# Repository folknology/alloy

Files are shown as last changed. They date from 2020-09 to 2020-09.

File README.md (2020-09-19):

# Alloy
Alloy an OpenSource hardware fusion of FPGA and WiFi Microcontroller in a [Feather](https://learn.adafruit.com/adafruit-feather/feather-specification) compatible layout, a project of the myStorm communtiy.

Current status is hardware prototype, you can see the developments we are making on my regular streams :
*  [Live Stream, 8pm BST](https://www.twitch.tv/folknology)
* [Historic streams](https://www.youtube.com/watch?v=79OoLG_Dxk0&list=PLXS9jyX9czzodpJNL-szsMfl0rOrZk4B7)
Or at the join us at the [myStorm community forum](https://forum.mystorm.uk)

We will be using an Alloy fusion framework on top of [nMigen](https://github.com/m-labs/nmigen) and [Circuit Python](https://github.com/adafruit/circuitpython)

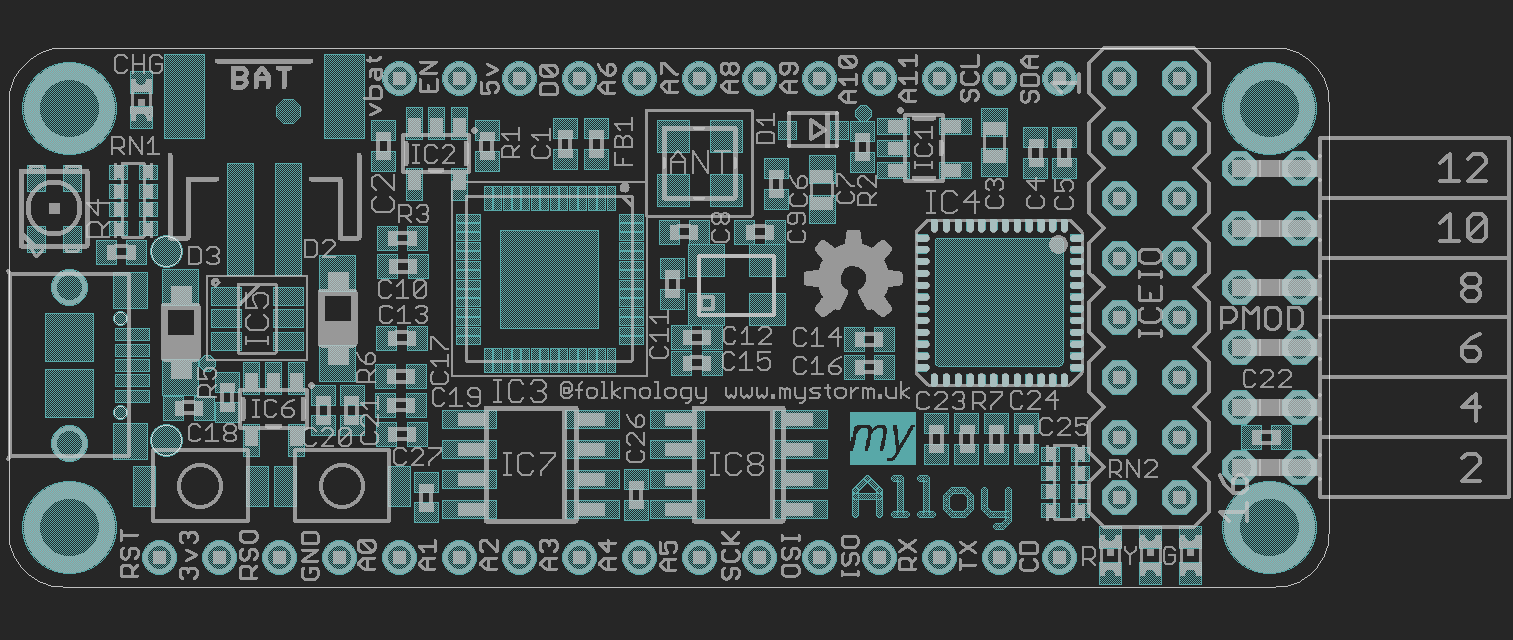
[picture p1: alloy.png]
Alloy


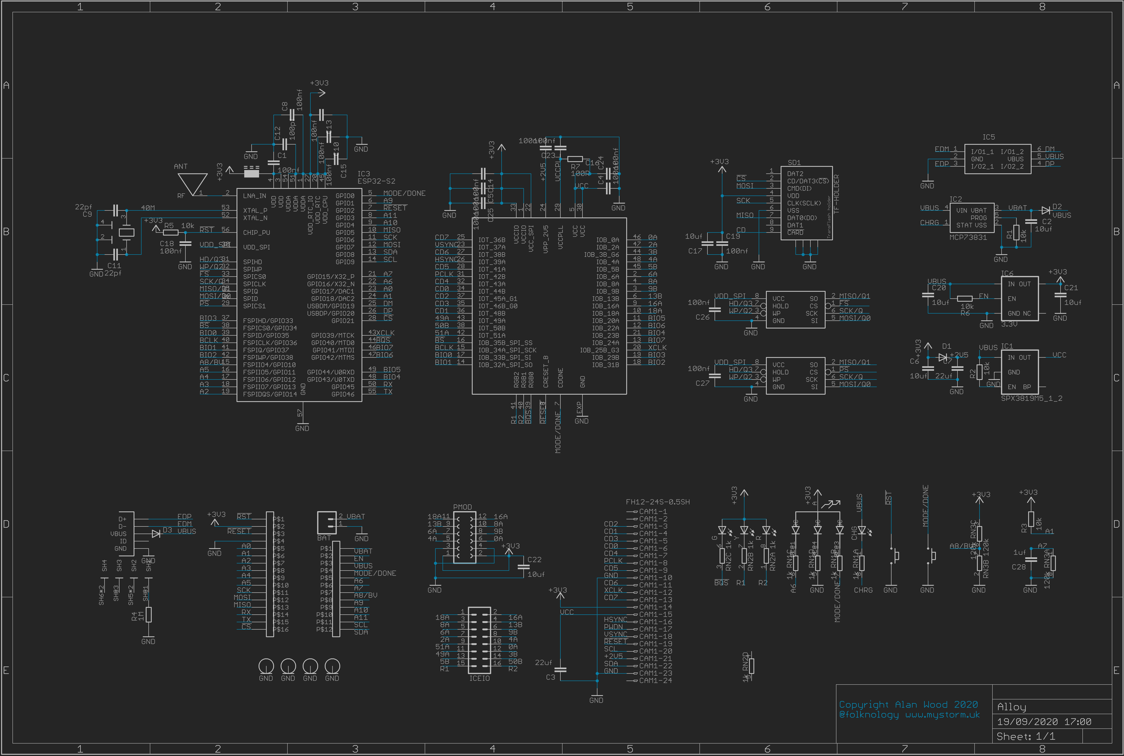
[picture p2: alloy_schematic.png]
Alloy


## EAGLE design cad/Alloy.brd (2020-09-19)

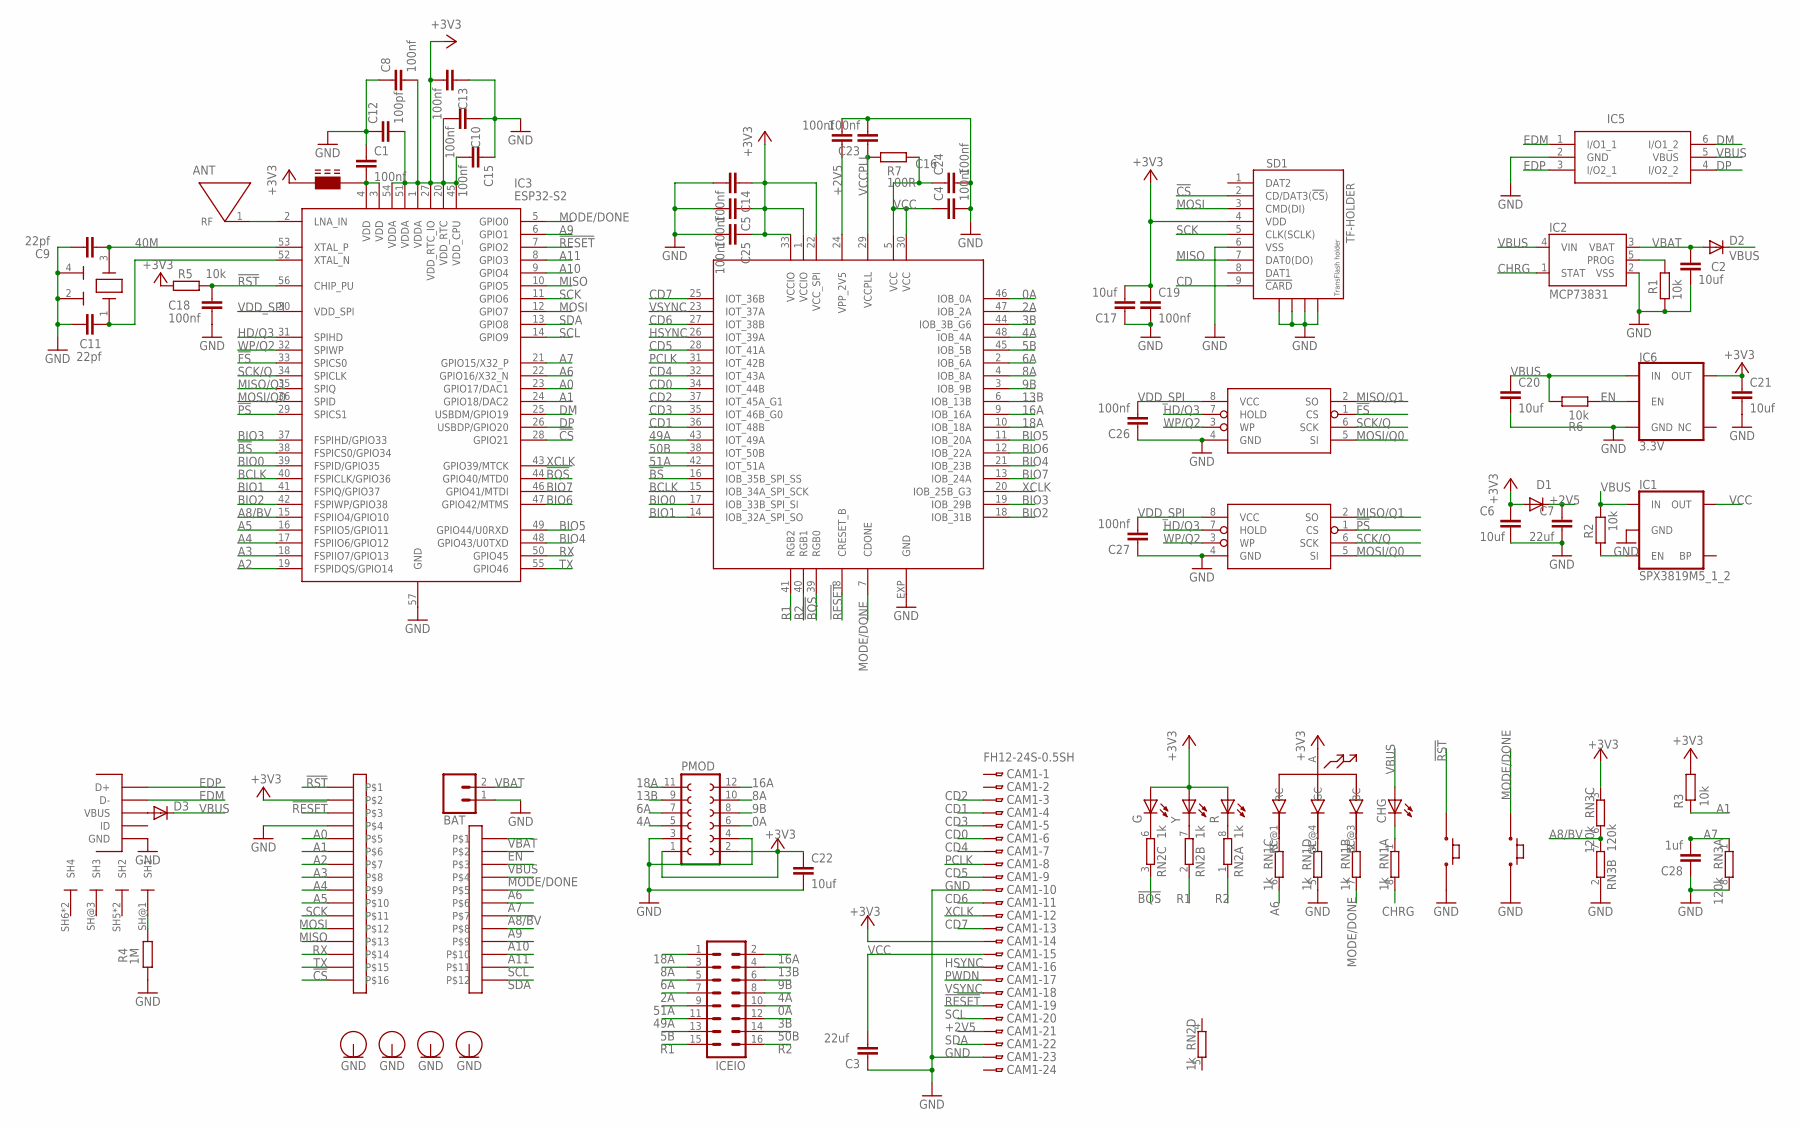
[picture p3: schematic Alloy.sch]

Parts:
ANT: 206513-0001; 2065130001
BAT: CONN_02-JST-2MM-SMT; JST-2-SMD
C1, C4, C5, C8, C10, C13, C14, C15, C16, C18, C19, C23, C24, C25, C26, C27: 100nf; C0402
C2, C6, C17, C20, C21, C22: 10uf; C0402
C3, C7: 22uf; C0603
C9, C11: 22pf; C0402
C12: 100pf; C0402
C28: 1uf; C0402
CAM1: FH12-24S-0.5SH
CHG: LEDCHIPLED_0603; CHIPLED_0603
D1: DIODE-SOD323-R; SOD323-R
D2, D3: DIODE-SOD123; SOD123
FB1: FERRITE_BEAD0402S; 0402S
FCL: 2.54-HEADER-16WTH-NS; 2.54_HEADER_16W_NS
FCU: 12X1X2.54-HEADERTH-NS; 2.54_HEADER_12W_NS
G: LEDCHIPLED_0603; CHIPLED_0603
H1, H2, H3, H4: HOLE2.5MM; 2.5MM-HOLE
IC1: SPX3819M5_1_2; SOT23-5
IC2: MCP73831; SOT23-5
IC3: ESP32-S2; QFN40P700X700X90-57N
IC4: ICE40UP5K; QFN48
IC5: USBLC6-2SC6; SOT95P280X145-6N
IC6: 3.3V; SOT23-5
IC7: LY68LXXXX; SO8
IC8: AT25SDF041A; SOIC-8-NARROW
ICEIO: MA08-2
PMOD: FE06-2W
R: LEDCHIPLED_0603; CHIPLED_0603
R1, R2, R3, R5, R6: 10k; R0402
R4: 1M; R0402
R7: 100R; R0402
RN1, RN2: 1k; 0603-ARV
RN3: 120k; 0603-ARV
SD1: TF-HOLDER; TF-PULL
U$1: RGB-PLCC-4; PLCC-4-SMALL
U$2: FCI-MICROUSB-B-PEG; MICROUSB-B-PEG
U$3, U$4: PUSH_BUTTON; 3X4MM_BUTTON
Y: LEDCHIPLED_0603; CHIPLED_0603
Y2: 12MZ; CRYSTAL-3.2X2.5

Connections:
0A: IC4.46 (IOB_0A), ICEIO.10, PMOD.6
2A: IC4.47 (IOB_2A), ICEIO.7
3B: IC4.44 (IOB_3B_G6), ICEIO.12
4A: IC4.48 (IOB_4A), ICEIO.8, PMOD.5
5B: IC4.45 (IOB_5B), ICEIO.13
6A: IC4.2 (IOB_6A), ICEIO.5, PMOD.7
8A: IC4.4 (IOB_8A), ICEIO.3, PMOD.10
9B: IC4.3 (IOB_9B), ICEIO.6, PMOD.8
13B: IC4.6 (IOB_13B), ICEIO.4, PMOD.9
16A: IC4.9 (IOB_16A), ICEIO.2, PMOD.12
18A: IC4.10 (IOB_18A), ICEIO.1, PMOD.11
40M: C9.2, IC3.53 (XTAL_P), Y2.3 (X2)
49A: IC4.43 (IOT_49A), ICEIO.11
50B: IC4.38 (IOT_50B), ICEIO.14
51A: IC4.42 (IOT_51A), ICEIO.9
!BQS: IC3.44 (GPIO40/MTD0), IC4.39 (RGB0), RN2.3 (1)
!BS: IC3.38 (FSPICS0/GPIO34), IC4.16 (IOB_35B_SPI_SS)
!CS: FCL.16, IC3.28 (GPIO21), SD1.2 (CD/DAT3(!CS!))
!FS: IC3.33 (SPICS0), IC8.1 (CS)
!PS: IC3.29 (SPICS1), IC7.1 (CS)
!RESET: CAM1.19, FCL.3, IC3.7 (GPIO2), IC4.8 (CRESET_B)
!RST: C18.1, FCL.1, IC3.56 (CHIP_PU), R5.1, U$3.P$1
+2V5: C7.2, C16.1, CAM1.21, D1.C, IC4.24 (VPP_2V5)
+3V3: C5.1, C6.1, C8.2, C10.2, C12.2, C13.2, C14.1, C15.2, C17.2, C19.1, C21.1, C22.1, C25.1, CAM1.14, D1.A, FB1.1, FCL.2, G.A, IC3.1 (VDDA), IC3.20 (VDD_RTC), IC3.27 (VDD_RTC_IO), IC3.45 (VDD_CPU), IC3.51 (VDDA), IC3.54 (VDDA), IC4.1 (VCCIO), IC4.22 (VCC_SPI), IC4.33 (VCCIO), IC6.5 (OUT), PMOD.1, PMOD.2, R.A, R3.1, R5.2, RN3.3 (1), SD1.4 (VDD), U$1.A (ANODE), Y.A
A0: FCL.5, IC3.23 (GPIO17/DAC1)
A1: FCL.6, IC3.24 (GPIO18/DAC2), R3.2
A2: FCL.7, IC3.19 (FSPIDQS/GPIO14)
A3: FCL.8, IC3.18 (FSPIIO7/GPIO13)
A4: FCL.9, IC3.17 (FSPIIO6/GPIO12)
A5: FCL.10, IC3.16 (FSPIIO5/GPIO11)
A6: FCU.5, IC3.22 (GPIO16/X32_N), RN1.6 (2)
A7: C28.2, FCU.6, IC3.21 (GPIO15/X32_P), RN3.1
A8/BV: FCU.7, IC3.15 (FSPIIO4/GPIO10), RN3.6 (2), RN3.7 (2)
A9: FCU.8, IC3.6 (GPIO1)
A10: FCU.9, IC3.9 (GPIO4)
A11: FCU.10, IC3.8 (GPIO3)
BCLK: IC3.40 (FSPICLK/GPIO36), IC4.15 (IOB_34A_SPI_SCK)
BIO0: IC3.39 (FSPID/GPIO35), IC4.17 (IOB_33B_SPI_SI)
BIO1: IC3.41 (FSPIQ/GPIO37), IC4.14 (IOB_32A_SPI_SO)
BIO2: IC3.42 (FSPIWP/GPIO38), IC4.18 (IOB_31B)
BIO3: IC3.37 (FSPIHD/GPIO33), IC4.19 (IOB_29B)
BIO4: IC3.48 (GPIO43/U0TXD), IC4.21 (IOB_23B)
BIO5: IC3.49 (GPIO44/U0RXD), IC4.11 (IOB_20A)
BIO6: IC3.47 (GPIO42/MTMS), IC4.12 (IOB_22A)
BIO7: IC3.46 (GPIO41/MTDI), IC4.13 (IOB_24A)
CD: SD1.9 (!CARD)
CD0: CAM1.6, IC4.34 (IOT_44B)
CD1: CAM1.4, IC4.36 (IOT_48B)
CD2: CAM1.3, IC4.37 (IOT_45A_G1)
CD3: CAM1.5, IC4.35 (IOT_46B_G0)
CD4: CAM1.7, IC4.32 (IOT_43A)
CD5: CAM1.9, IC4.28 (IOT_41A)
CD6: CAM1.11, IC4.27 (IOT_38B)
CD7: CAM1.13, IC4.25 (IOT_36B)
CHRG: IC2.1 (STAT), RN1.8 (2)
DM: IC3.25 (USBDM/GPIO19), IC5.6 (I/O1_2)
DP: IC3.26 (USBDP/GPIO20), IC5.4 (I/O2_2)
EDM: IC5.1 (I/O1_1), U$2.P$2 (D-)
EDP: IC5.3 (I/O2_1), U$2.P$3 (D+)
EN: FCU.2, IC6.3 (EN), R6.2
GND: BAT.1 (2), C1.1, C2.2, C3.1, C4.2, C5.2, C6.2, C7.1, C8.1, C9.1, C10.1, C11.1, C12.1, C13.1, C14.2, C15.1, C16.2, C17.1, C18.2, C19.2, C20.2, C21.2, C22.2, C23.2, C24.2, C25.2, C26.1, C27.1, C28.1, CAM1.10, CAM1.23, FCL.4, H1.P$1, H2.P$1, H3.P$1, H4.P$1, IC1.2 (GND), IC2.2 (VSS), IC3.57 (GND), IC4.EXP (GND), IC5.2 (GND), IC6.2 (GND), IC7.4 (GND), IC8.4 (GND), PMOD.3, PMOD.4, R1.2, R4.2, RN1.5 (2), RN3.2 (1), RN3.8 (2), SD1.6 (VSS), SD1.S1, SD1.S2, SD1.S3, SD1.S4, U$2.P$5 (GND), U$3.P$2, U$4.P$2, Y2.2 (GND), Y2.4 (GND)
HD/Q3: IC3.31 (SPIHD), IC7.7 (HOLD), IC8.7 (HOLD)
HSYNC: CAM1.16, IC4.26 (IOT_39A)
MISO: FCL.13, IC3.10 (GPIO5), SD1.7 (DAT0(DO))
MISO/Q1: IC3.35 (SPIQ), IC7.2 (SO), IC8.2 (SO)
MODE/DONE: FCU.4, IC3.5 (GPIO0), IC4.7 (CDONE), RN1.7 (2), U$4.P$1
MOSI: FCL.12, IC3.12 (GPIO7), SD1.3 (CMD(DI))
MOSI/Q0: IC3.36 (SPID), IC7.5 (SI), IC8.5 (SI)
unnamed: IC2.5 (PROG), R1.1
unnamed: ANT.1 (RF), IC3.2 (LNA_IN)
unnamed: IC1.3 (EN), R2.2
unnamed: R.C, RN2.8 (2)
unnamed: RN2.7 (2), Y.C
unnamed: C1.2, FB1.2, IC3.3 (VDD), IC3.4 (VDD)
unnamed: G.C, RN2.6 (2)
unnamed: R4.1, U$2.SH@1 (SH1)
unnamed: CHG.C, RN1.1
unnamed: D3.A, U$2.P$1 (VBUS)
unnamed: RN1.4 (1), U$1.GC@4 (GC)
unnamed: RN1.3 (1), U$1.RC@1 (RC)
unnamed: RN1.2 (1), U$1.BC@3 (BC)
unnamed: C11.2, IC3.52 (XTAL_N), Y2.1 (X1)
PCLK: CAM1.8, IC4.31 (IOT_42B)
PWDN: CAM1.17
R1: IC4.41 (RGB2), ICEIO.15, RN2.2 (1)
R2: IC4.40 (RGB1), ICEIO.16, RN2.1
RX: FCL.14, IC3.50 (GPIO45)
SCK: FCL.11, IC3.11 (GPIO6), SD1.5 (CLK(SCLK))
SCK/Q: IC3.34 (SPICLK), IC7.6 (SCK), IC8.6 (SCK)
SCL: CAM1.20, FCU.11, IC3.14 (GPIO9)
SDA: CAM1.22, FCU.12, IC3.13 (GPIO8)
TX: FCL.15, IC3.55 (GPIO46)
VBAT: BAT.2 (1), C2.1, D2.A, FCU.1, IC2.3 (VBAT)
VBUS: C20.1, CHG.A, D2.C, D3.C, FCU.3, IC1.1 (IN), IC2.4 (VIN), IC5.5 (VBUS), IC6.1 (IN), R2.1, R6.1
VCC: C3.2, C4.1, C24.1, CAM1.15, IC1.5 (OUT), IC4.5 (VCC), IC4.30 (VCC), R7.1
VCCPLL: C23.1, IC4.29 (VCCPLL), R7.2
VDD_SPI: C26.2, C27.2, IC3.30 (VDD_SPI), IC7.8 (VCC), IC8.8 (VCC)
VSYNC: CAM1.18, IC4.23 (IOT_37A)
WP/Q2: IC3.32 (SPIWP), IC7.3 (WP), IC8.3 (WP)
XCLK: CAM1.12, IC3.43 (GPIO39/MTCK), IC4.20 (IOB_25B_G3)

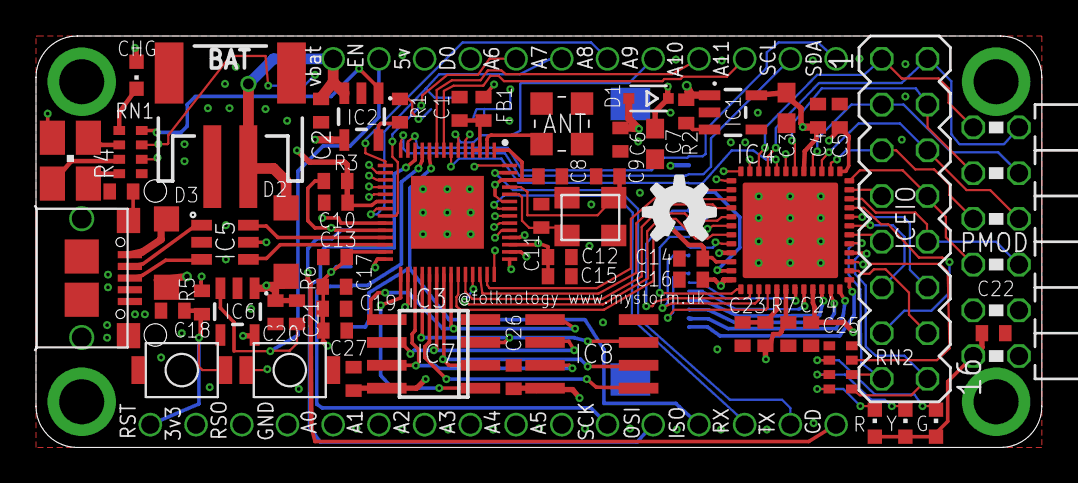
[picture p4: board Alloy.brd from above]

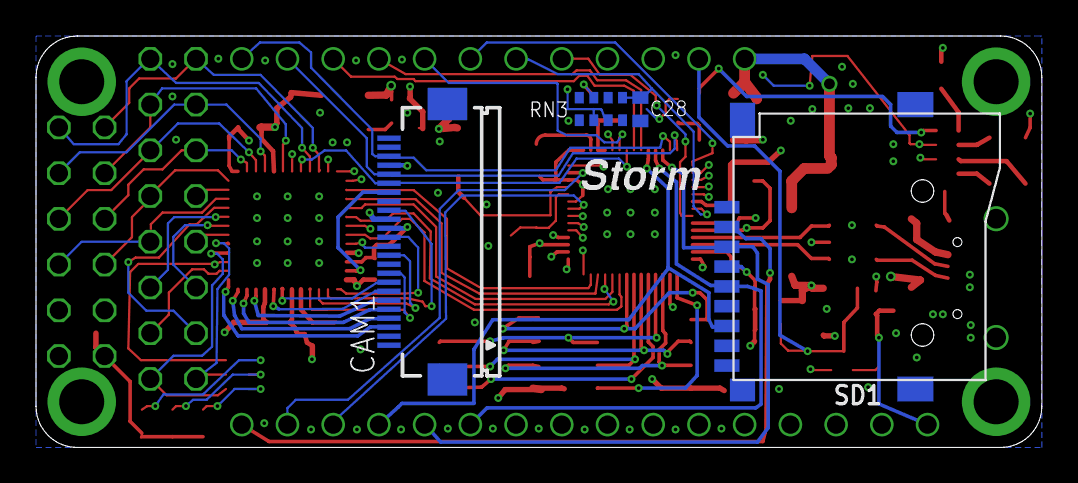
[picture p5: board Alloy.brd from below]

Board: 4 copper layers, 55.9 x 22.9 mm, 71 parts (4 on the bottom side), 98 nets.

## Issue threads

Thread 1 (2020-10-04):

Pin conflict between camera and PLL

daveshah1, 2020-10-04:
Had a glance of the schematic. Pins 35 and 37 of the iCE40 look like they are used for camera input, but these pins are output only when the PLL is used. Might be worth reconsidering this if there is a use case for both the camera and PLL at the same time.

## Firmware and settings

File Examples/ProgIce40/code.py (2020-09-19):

import board
import digitalio
import time

def not_eof(f):
    s = f.read(1)
    if s != b'':    # restore position
        f.seek(-1, 1)
    return s != b''


def write_byte(bite):
    if bite == 0:
        sout.value = False
        for _ in range(8):
            clk.value = False
            clk.value = True
    else:
        bits = bin(bite)[2:]
        sout.value = False
        for _zero in range(8 - len(bits)):
            clk.value = False
            clk.value = True

        for bit in bits:
            clk.value = False
            if bit == '0':
                sout.value = False
            else:
                sout.value = True
            clk.value = True


def dummy_clocks(clocks):
    for _dummy in range(clocks):
        clk.value = False
        sout.value = False
        clk.value = True


def flush_bytes():
    for x in range(50):
        write_byte(0x01)


def write_bytes(bitfile):
    byte_count = 0
    while True: #not_eof(bitfile)
        byte_count = byte_count + 64
        bites = f.read(64)
        if byte_count > num_bytes:
            break
        else:
            for b in bites:
                write_byte(b) # int.from_bytes(b, 0)

    print("Wrote {} bytes".format(byte_count))

sig = b'\x7e\xaa\x99\x7e'#b'~\xaa\x99~'
num_bytes = 104161

rst = digitalio.DigitalInOut(board.IO33)
rst.direction = digitalio.Direction.OUTPUT
ssel = digitalio.DigitalInOut(board.IO34)
ssel.direction = digitalio.Direction.OUTPUT
clk = digitalio.DigitalInOut(board.IO36)
clk.direction = digitalio.Direction.OUTPUT
sout = digitalio.DigitalInOut(board.IO35)
sout.direction = digitalio.Direction.OUTPUT

ssel.value = True
rst.value = False
ssel.value = False
clk.value = True
time.sleep(0.2)
rst.value = True
time.sleep(1.2)
ssel.value = True
dummy_clocks(8)
ssel.value = False

try:
    f = open("/logic.bin", "rb")
except OSError:
    print("Couldn't open file")

print("File opened")

try:
    byte_count = 0
    while not_eof(f):
        byte_count = byte_count + 1
        hex = f.read(1)
        #print(hex)
        if hex == b'\x7e':  # 0xAA
            f.seek(-1,1)
            hex = f.read(4)
            if hex == sig:
                print('Found bitimg sig: {} at {}'.format(hex, byte_count))
                f.seek(-4,1)
                write_bytes(f)
                break

    #flush_bytes()
    ssel.value = True
    dummy_clocks(100)
    dummy_clocks(49)


except OSError:
    print("Couldn't read logic bitfile")
finally:
    f.close()
print("Finished Programming")

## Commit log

2020-09-19 Added initial Cad schematic and PCB files
    [Alloy.brd, Alloy.sch]
2020-09-19 Added Solderpad opensource hardware license
2020-09-19 Added current state of project to the readme
2020-09-19 Added the schematic image
    [Alloy.sch]
2020-09-19 Added a really basic CP example of programming the Ice40 from the ESP32-S2 which is bit banged DPI until I get scot's changes merged

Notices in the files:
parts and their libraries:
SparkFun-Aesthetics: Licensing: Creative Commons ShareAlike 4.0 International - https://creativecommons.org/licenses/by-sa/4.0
